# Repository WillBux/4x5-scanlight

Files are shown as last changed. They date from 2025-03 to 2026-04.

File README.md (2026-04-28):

# A Better Large Format Light Source For Scanning Color Negative Film

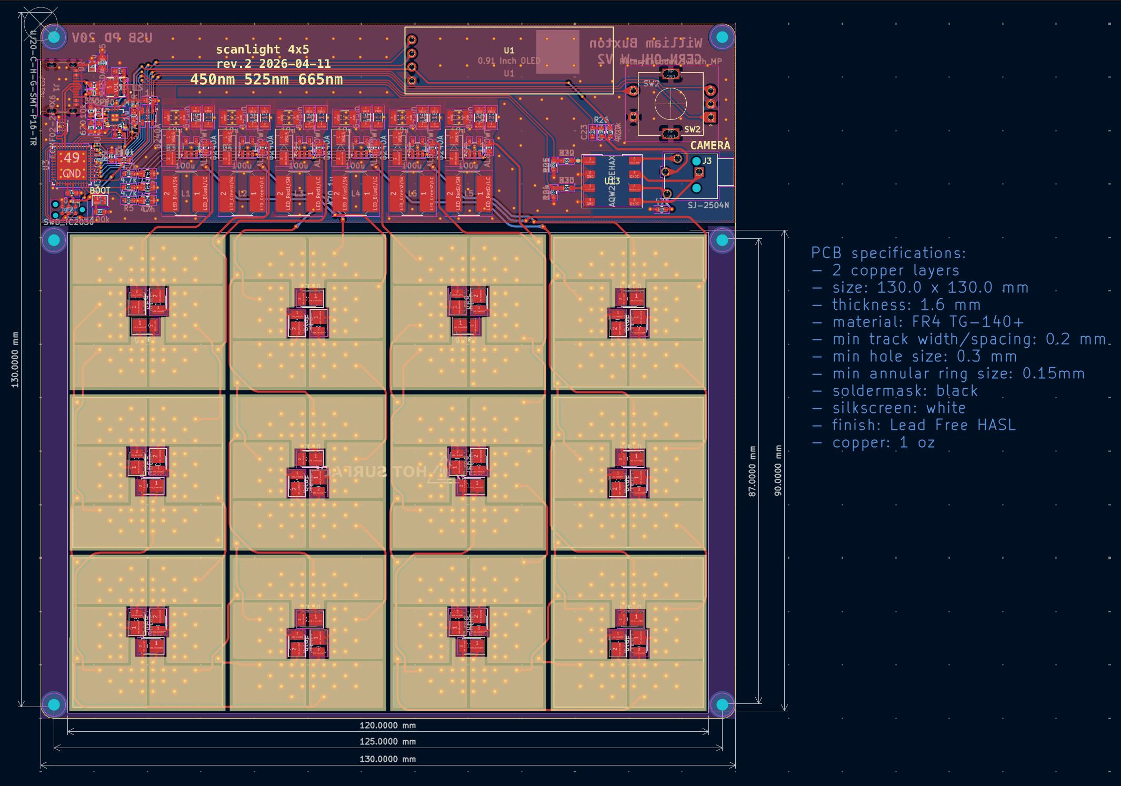
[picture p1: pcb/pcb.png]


<small>Originally published by [jackw01](https://github.com/jackw01/scanlight) on 2024-08-05, forked 2025-03-20</small>

## tl;dr

Read [Jack's GitHub Page](https://jackw01.github.io/scanlight/) for the theory behind the project.

# Major Changes

This fork is a major redesign of the Scanlight project. 
The main purpose is to expand the size to allow for scanning 4x5 large format film. 

The number of LEDs have been doubled to 12 per color (deep red 660nm; green 525nm; royal blue 450nm) and the 3D printed shroud has been adjusted likewise.
A slightly different [red led](https://www.digikey.ch/en/products/detail/lumileds/L1SP-DRD0002800000/9805570) has been chosen 
to better match the [Spectral-Sensitivity Curve of Portra 160](https://business.kodakmoments.com/sites/default/files/files/resources/e4051_Portra_160.pdf) (and it is cheaper at the time of writing).

This project incorporates a microcontroller (STM32G0B1) which more precisely controls the brightness of each LED channel.
Brightness values can be stored through power off states for repeatable scans. 
Additionally, the microcontroller is responsible for USB-PD (20V is necessary, ~1.25A required for maximum brightness)



[Schematic (PDF)](pcb/schematic.pdf)

[BOM](pcb/bom/ibom.html)

#### Build Notes

The PCB should be fabricated similar to [jackw01/scanlight](https://github.com/jackw01/scanlight), that is a black soldermask and white silkscreen. 

As modified, only a 20V-capable USB PD supply can be used. All parts were sourced on DigiKey.

### The Diffuser

The diffuser stack up has not changed from [jackw01/scanlight](https://github.com/jackw01/scanlight).
Only the 3D printed enclosure has been enlarged. 

I printed the parts in black PETG and installed aluminum tape on the insides to improve efficiency.

Additional parts: 
- 4x M2x6mm socket head cap screws
- 4x M2x10mm socket head cap screws
- 8x M2 square nuts (DIN 562)

### Status and the Future

The backlight has been working great for my scanning! 
I recently redesigned the PCB to add a 2.5mm jack output for a shutter sync.
This enables the ability to scan automatically with separate RGB channels.
This feature is enabled when the 2.5mm jack is plugged in.
I will update the README when my PCBs arrive and I successfully test the feature. 

In the distant future I plan on incorporating this into my enlarger to print 4x5 (and 120) negatives.
I no longer shoot 35mm and probably will not produce a 35mm mask for scanning and printing.
If you only shoot 35mm I recommend using Jack's design as it is smaller and cheaper. 

## license

The PCB schematic, layout, and Gerber files and the 3D CAD files for this project are released under the CERN Open Hardware Licence Version 2 - Weakly Reciprocal (CERN-OHL-W V2).

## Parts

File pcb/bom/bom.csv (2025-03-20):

Reference | Value | Footprint | Qty | DNP | MPN
C1,C2 | 330p | Capacitor_SMD:C_0603_1608Metric | 2 |  | Generic 330pF 50V C0G/NP0 0603
C3 | 4.7u | Capacitor_SMD:C_0805_2012Metric | 1 |  | Generic 4.7uF 50V X7R 0805
C4,C8,C9,C14,C15,C18,C19,C22 | 1u | Capacitor_SMD:C_0603_1608Metric | 8 |  | Generic 1uF 50V X7R 0603 X7R
C5,C6 | 0.1u | Capacitor_SMD:C_0603_1608Metric | 2 |  | Generic 0.1uF 50V X7R 0603
C7,C11,C13 | 47n | Capacitor_SMD:C_0805_2012Metric | 3 |  | Generic 0.047uF 50V X7R 0805
C10,C12,C16,C17,C20,C21 | 10u | Capacitor_SMD:C_1210_3225Metric | 6 |  | Generic 10uF 50V X7R 1210
D1 | BAT54K | Diode_SMD:D_SOD-523 | 1 |  | BAT54KFILM
D2 | ESDA25P35 | Diode_SMD:ST_QFN-2L_1.6x1.0mm | 1 |  | ESDA25P35-1U1M
D3,D4,D6,D7,D8,D21 | B240A | Diode_SMD:D_SMA | 6 |  | B240A-13-F
D5,D9,D12,D15,D20,D24,D27,D31,D34,D38,D41,D44 | red | LED_SMD:LED_PLCC_2835_Handsoldering_Reverse | 12 |  | L1SP-DRD0002800000
D10,D13,D17,D18,D22,D25,D29,D32,D33,D37,D39,D43 | green | LED_SMD:LED_PLCC_2835_Handsoldering | 12 |  | JE2835AGR-N-0002A0000-N0000001
D11,D14,D16,D19,D23,D26,D28,D30,D35,D36,D40,D42 | blue | LED_SMD:LED_PLCC_2835_Handsoldering | 12 |  | JE2835ARY-N-0002A0000-N0000001
J1 | UJ20-C-H-G-SMT-P16-TR | Custom:USB_C_Receptacle_UJ20-C-H-G-SMT-P16-TR | 1 |  | UJ20-C-H-G-SMT-P16-TR
J2 | SWD_TC2030 | Connector:Tag-Connect_TC2030-IDC-NL_2x03_P1.27mm_Vertical | 1
L1,L2,L3,L4,L5,L6 | 100u | Inductor_SMD:L_Bourns_SRN8040TA | 6 |  | HPC 8040NV-101M
Q1 | STL11N3LLH6 | Custom:POWERFLAT-3p3X3p3_STM | 1 |  | STL11N3LLH6
R1,R10 | 10k | Resistor_SMD:R_0603_1608Metric | 2 |  | Generic 10kΩ 5% 0603
R2 | 100k | Resistor_SMD:R_0603_1608Metric | 1 |  | Generic 100kΩ 1% 0603
R3 | 620 | Resistor_SMD:R_0603_1608Metric | 1 |  | Generic 620Ω 1% 0603
R4 | 200k | Resistor_SMD:R_0603_1608Metric | 1 |  | Generic 200kΩ 1% 0603
R5,R7,R8 | 4.7k | Resistor_SMD:R_0603_1608Metric | 3 |  | Generic 4.7kΩ 1% 0603
R6,R11,R12,R13,R14,R15,R16,R17,R18,R19,R20,R21 | 845m | Resistor_SMD:R_1206_3216Metric | 12 |  | Generic 845mΩ 1% 1206
R9 | 40.2k | Resistor_SMD:R_0603_1608Metric | 1 |  | Generic 40.2kΩ 1% 0603
SW1 | BOOT | Jumper:SolderJumper-2_P1.3mm_Open_TrianglePad1.0x1.5mm | 1
SW2 | RotaryEncoder_Switch_MP | Rotary_Encoder:RotaryEncoder_Alps_EC11E-Switch_Vertical_H20mm | 1 |  | EC11E
U1 | 0.91 Inch OLED | Display:0.91_Inch_OLED | 1 |  | Monochrome OLED 0.91" 128x32 (Aliexpress)
U2 | ECMF02-2AMX6 | Package_DFN_QFN:ST_UQFN-6L_1.5x1.7mm_P0.5mm | 1 |  | ECMF02-2AMX6
U3 | STM32G0B1CBUx | Package_DFN_QFN:QFN-48-1EP_7x7mm_P0.5mm_EP5.6x5.6mm | 1 |  | STM32G0B1CBU6
U4 | TCPP01_M12 | Custom:QFN-12-1EP_3x3mm_P0.50mm_EP1.45x1.45mm | 1 |  | TCPP01_M12
U5,U7,U8,U9,U10,U11 | AL8860WT | Package_TO_SOT_SMD:TSOT-23-5 | 6 |  | AL8860WT-7
U6 | ST732M33R | Package_TO_SOT_SMD:TSOT-23-5 | 1 |  | ST732M33R

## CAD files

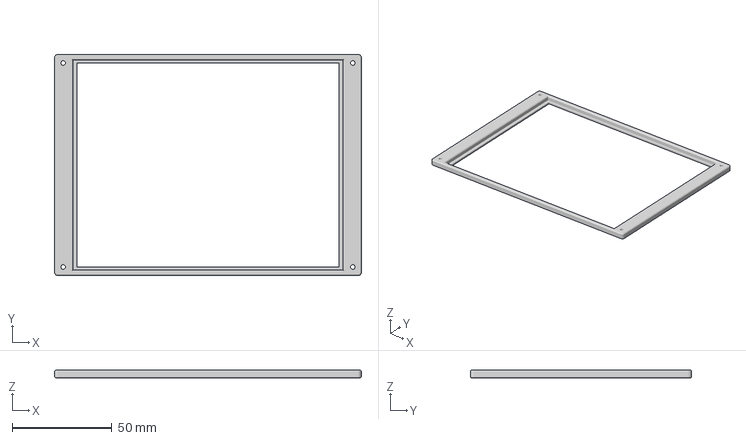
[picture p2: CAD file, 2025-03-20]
3d/Frame.3mf
153.5 x 110.7 x 4.00 mm

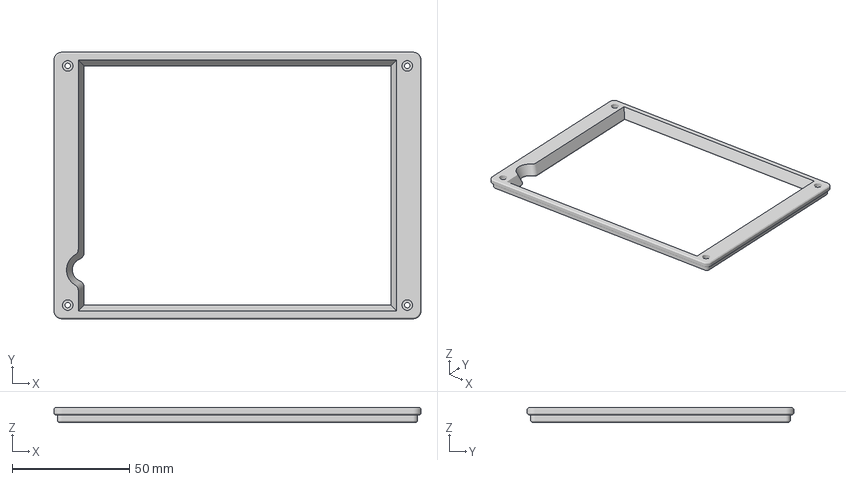
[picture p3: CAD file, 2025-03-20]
3d/CoverPlate.3mf
156.5 x 113.7 x 6.20 mm

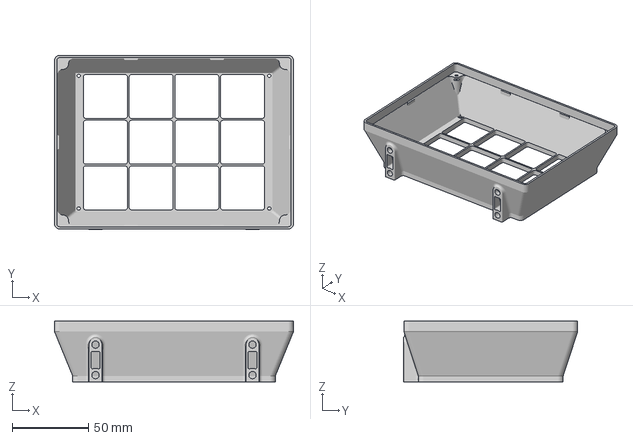
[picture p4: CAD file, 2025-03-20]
3d/Housing.3mf
156.8 x 114.4 x 40.0 mm

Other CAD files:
3d/scanlight.f3z

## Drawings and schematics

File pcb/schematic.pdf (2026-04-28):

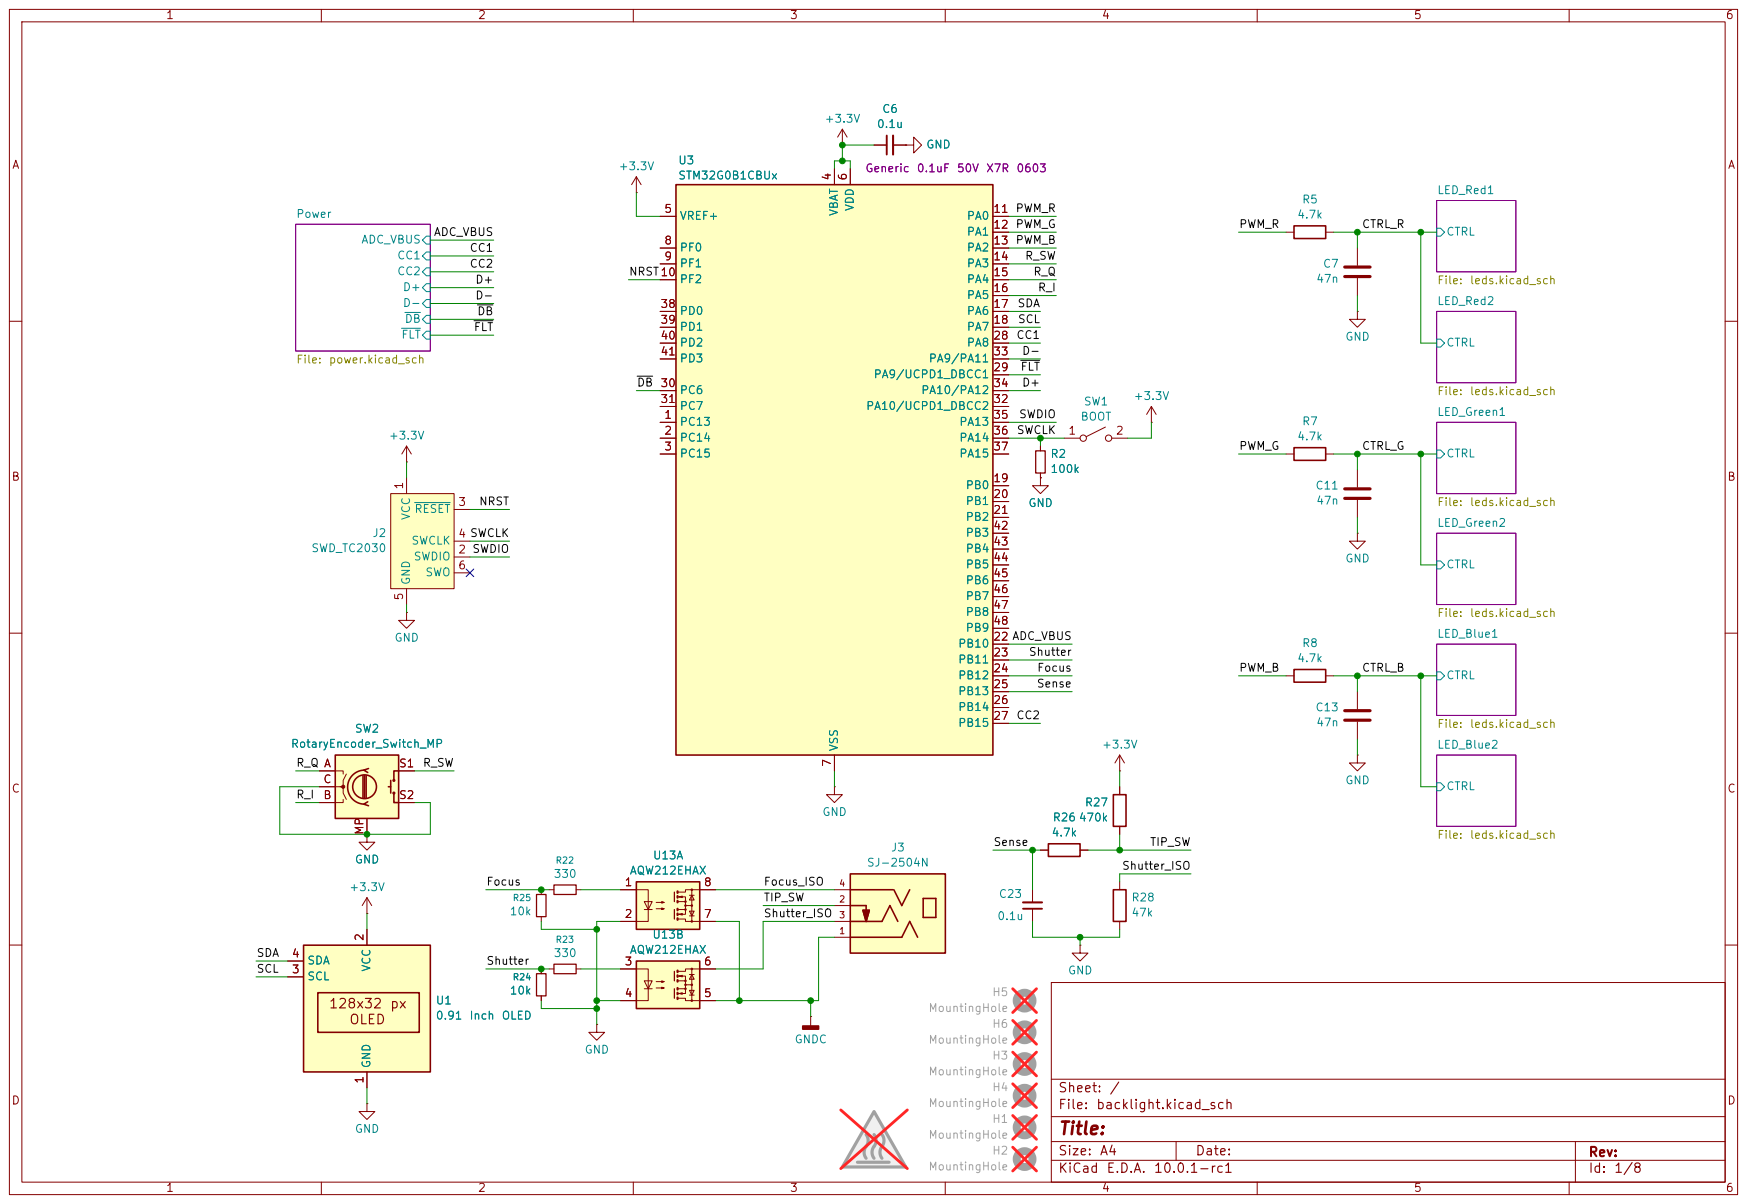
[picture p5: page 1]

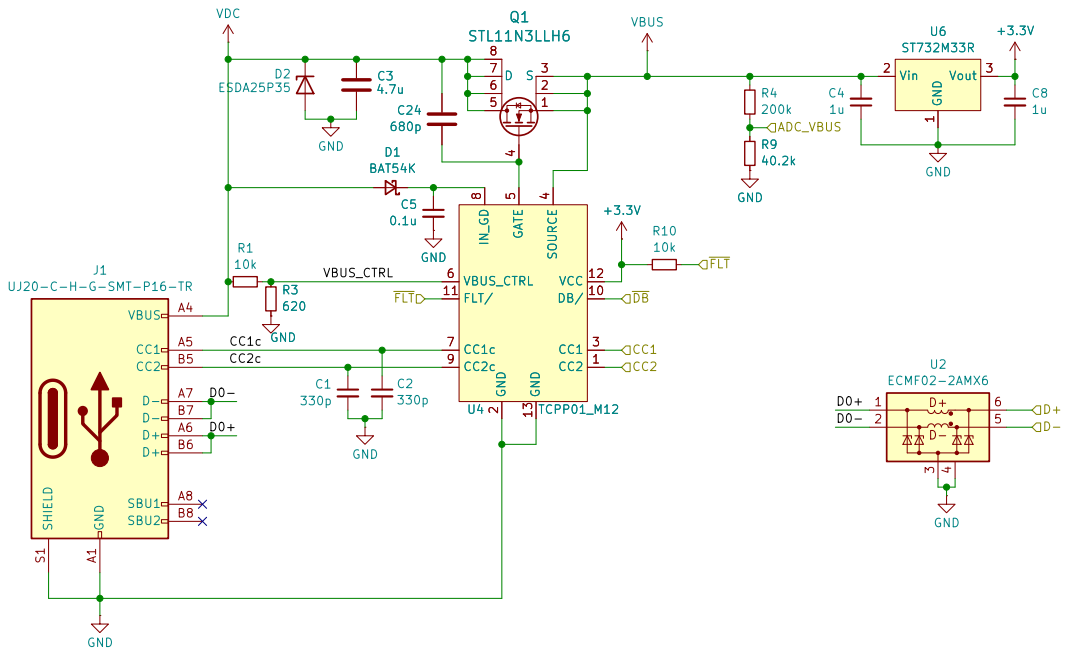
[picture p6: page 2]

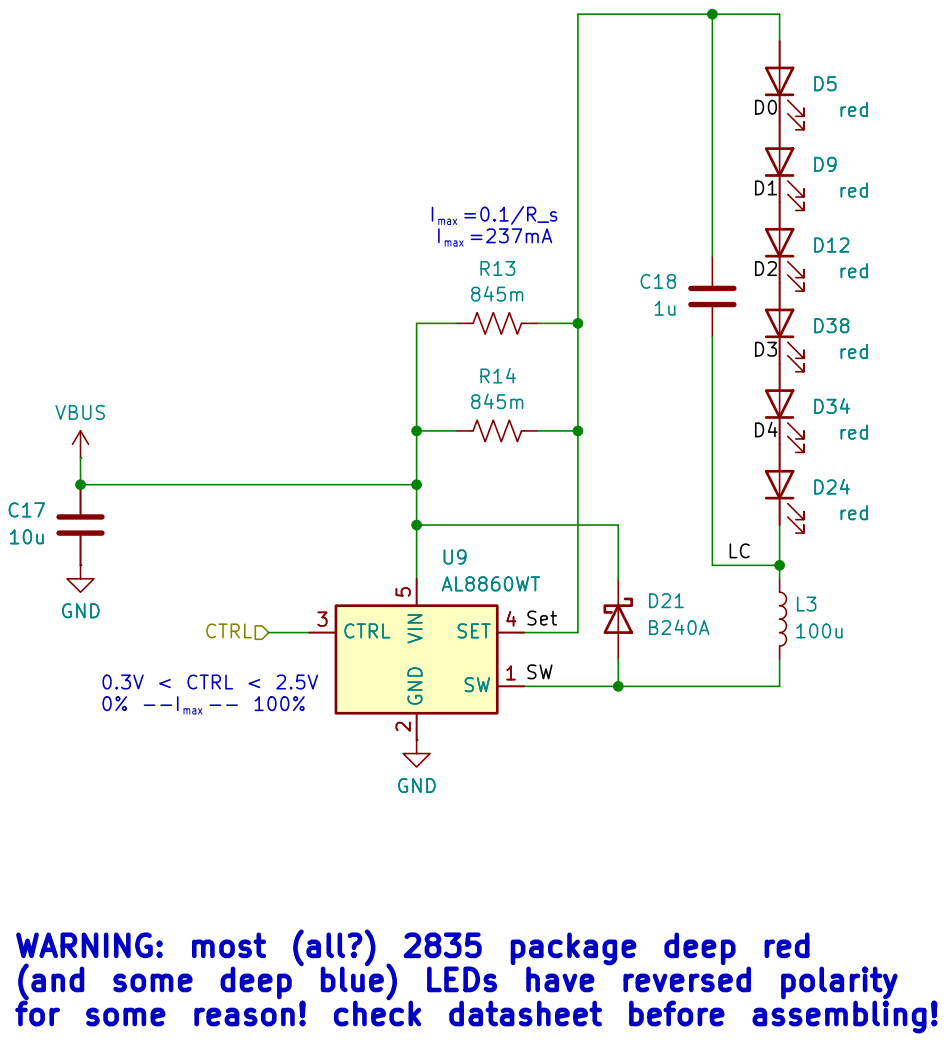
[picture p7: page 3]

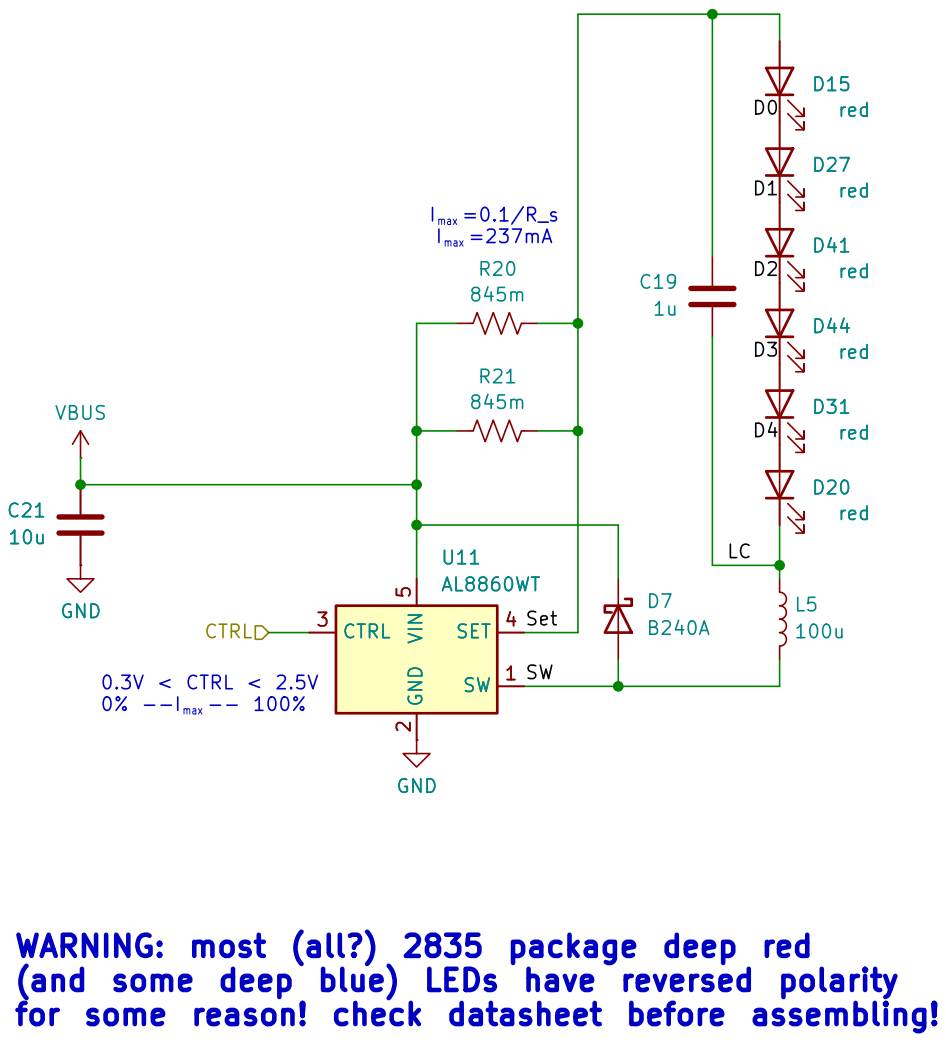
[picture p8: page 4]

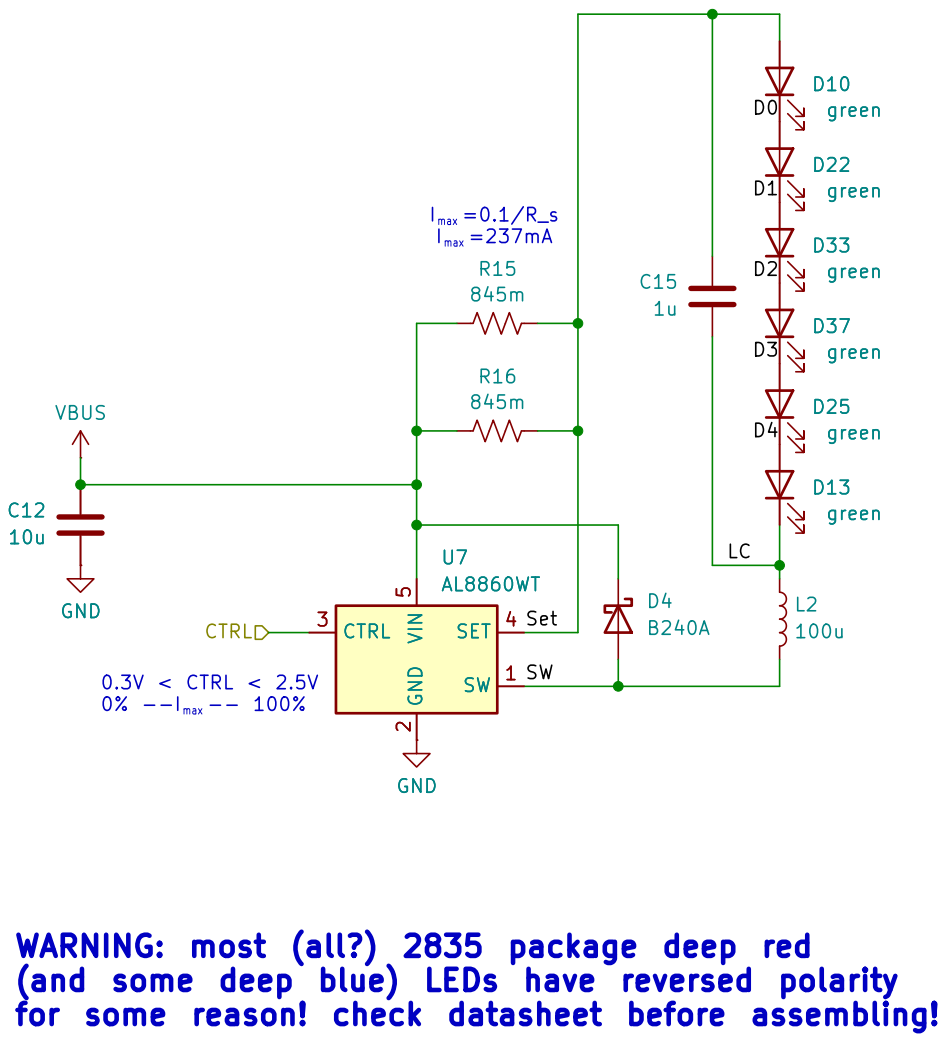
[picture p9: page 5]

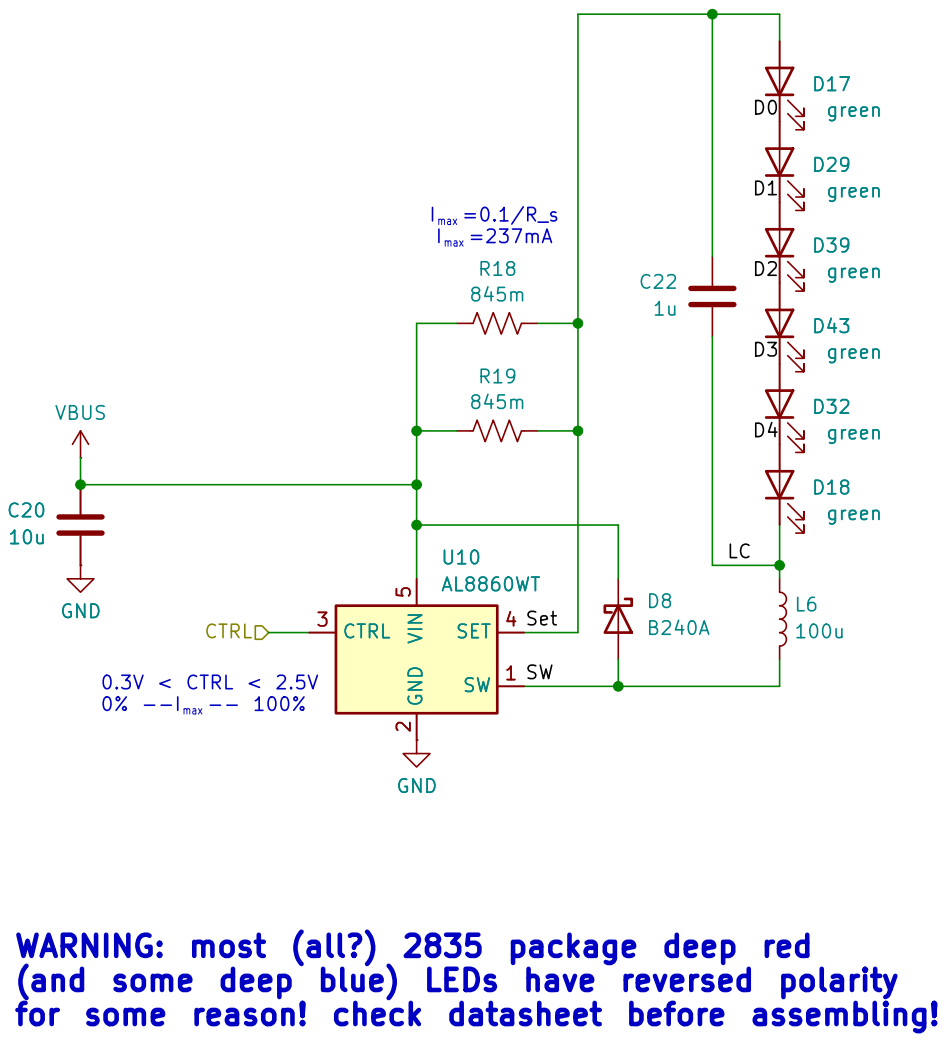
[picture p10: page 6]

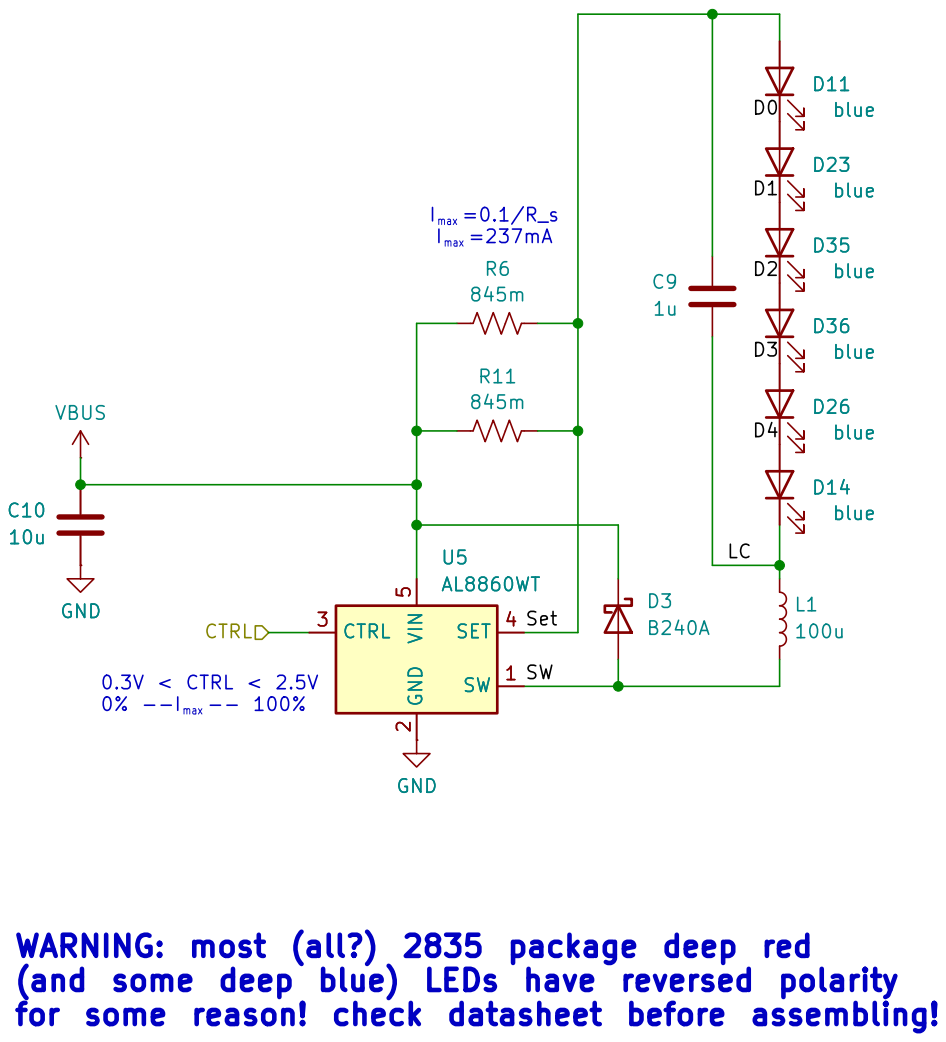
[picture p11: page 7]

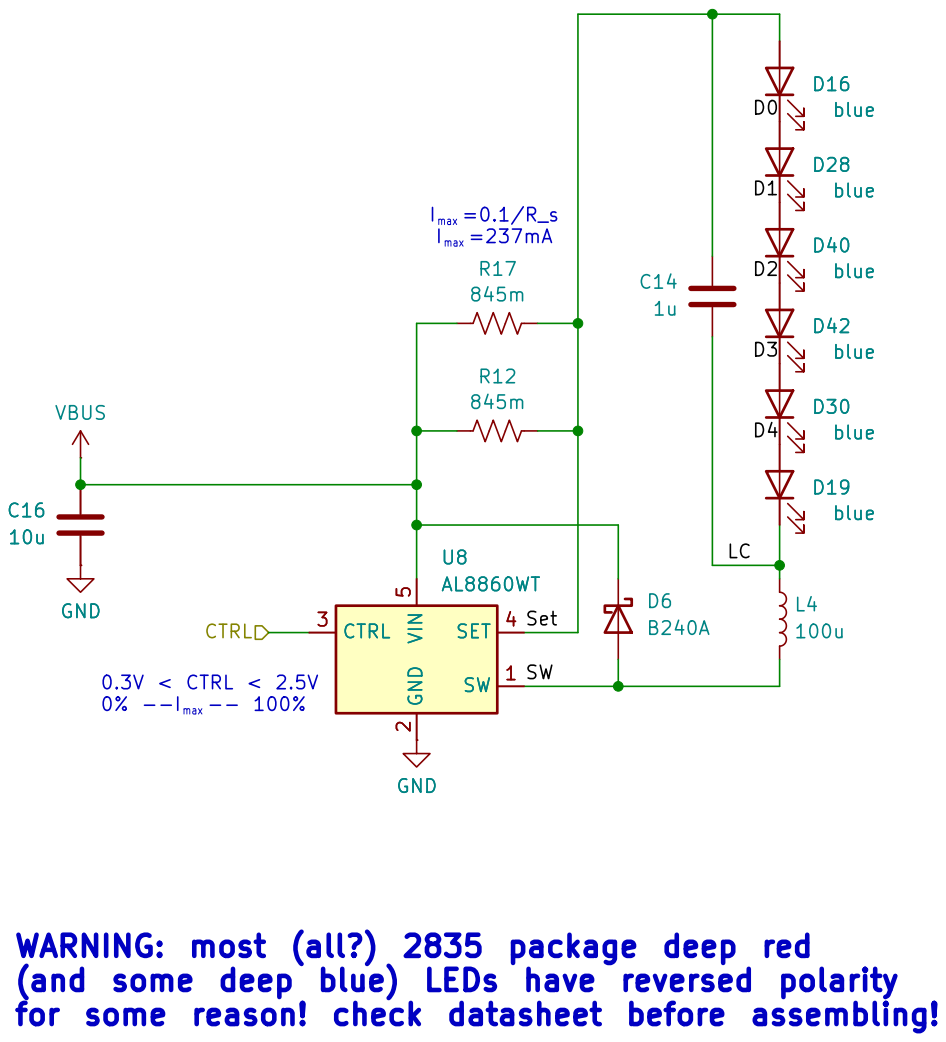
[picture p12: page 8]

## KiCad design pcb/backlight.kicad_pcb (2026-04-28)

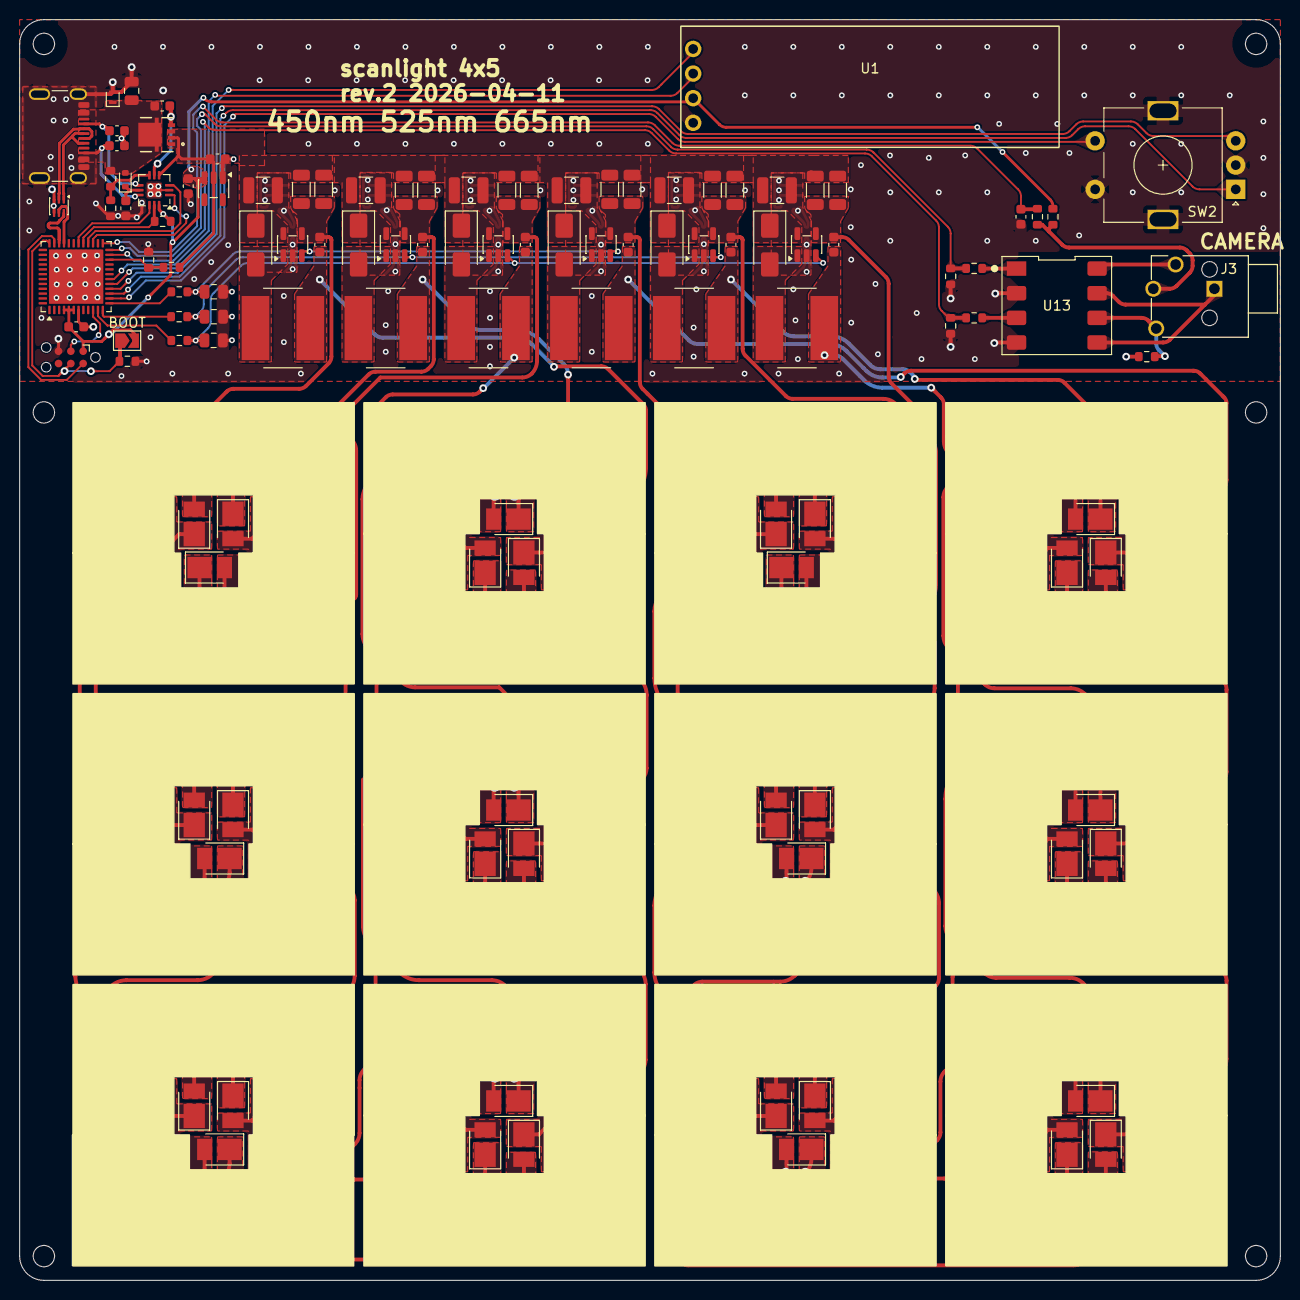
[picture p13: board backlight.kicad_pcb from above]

Board: 2 copper layers, 130.0 x 130.0 mm, 127 parts (1 on the bottom side), 89 nets.

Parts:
C1, C2: 330p; C_0603_1608Metric
C3: 4.7u; C_0805_2012Metric
C4, C8, C9, C14, C15, C18, C19, C22: 1u; C_0603_1608Metric
C5, C6, C23: 0.1u; C_0603_1608Metric
C7, C11, C13: 47n; C_0805_2012Metric
C10, C12, C16, C17, C20, C21: 10u; C_1210_3225Metric
C24: 680p; C_0603_1608Metric
D1: BAT54K; D_SOD-523
D2: ESDA25P35; ST_QFN-2L_1.6x1.0mm
D3, D4, D6, D7, D8, D21: B240A; D_SMA
D5, D9, D12, D15, D20, D24, D27, D31, D34, D38, D41, D44: red; LED_PLCC_2835_Handsoldering_Reverse
D10, D13, D17, D18, D22, D25, D29, D32, D33, D37, D39, D43: green; LED_PLCC_2835_Handsoldering
D11, D14, D16, D19, D23, D26, D28, D30, D35, D36, D40, D42: blue; LED_PLCC_2835_Handsoldering
H1, H2, H3, H4, H5, H6: MountingHole; MountingHole_2.2mm_M2_Mask_5mm
J1: UJ20-C-H-G-SMT-P16-TR; USB_C_Receptacle_UJ20-C-H-G-SMT-P16-TR
J2: SWD_TC2030; Tag-Connect_TC2030-IDC-NL_2x03_P1.27mm_Vertical
J3: SJ-2504N; CUI_SJ-2504N
L1, L2, L3, L4, L5, L6: 100u; L_Bourns_SRN8040TA
Q1: STL11N3LLH6; POWERFLAT-3p3X3p3_STM
R1, R10, R24, R25: 10k; R_0603_1608Metric
R2: 100k; R_0603_1608Metric
R3: 620; R_0603_1608Metric
R4: 200k; R_0603_1608Metric
R5, R7, R8, R26: 4.7k; R_0603_1608Metric
R6, R11, R12, R13, R14, R15, R16, R17, R18, R19, R20, R21: 845m; R_1206_3216Metric
R9: 40.2k; R_0603_1608Metric
R22, R23: 330; R_0603_1608Metric
R27: 470k; R_0603_1608Metric
R28: 47k; R_0603_1608Metric
SW1: BOOT; SolderJumper-2_P1.3mm_Open_TrianglePad1.0x1.5mm
SW2: RotaryEncoder_Switch_MP; RotaryEncoder_Alps_EC11E-Switch_Vertical_H20mm
SYM1: SYM_Hot_Large; HOT
U1: 0.91 Inch OLED; 0.91_OLED_Display
U2: ECMF02-2AMX6; ST_UQFN-6L_1.5x1.7mm_P0.5mm
U3: STM32G0B1CBUx; QFN-48-1EP_7x7mm_P0.5mm_EP5.6x5.6mm
U4: TCPP01_M12; QFN-12-1EP_3x3mm_P0.50mm_EP1.45x1.45mm
U5, U7, U8, U9, U10, U11: AL8860WT; TSOT-23-5
U6: ST732M33R; TSOT-23-5
U13: AQW212EHAX; DIP-8_W8.3_SMDSocket

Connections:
+3.3V: C6.1, C8.1, J2.1 (VCC), R10.1, R27.2, SW1.2 (B), U1.2 (VCC), U3.4 (VBAT), U3.5 (VREF+), U3.6 (VDD), U4.12 (VCC), U6.3 (Vout)
/ADC_VBUS: R4.2, R9.1, U3.22 (PB10)
/CC1: U3.28 (PA8), U4.3 (CC1)
/CC2: U3.27 (PB15), U4.1 (CC2)
/CTRL_B: C13.1, R8.1, U5.3 (CTRL), U8.3 (CTRL)
/CTRL_G: C11.1, R7.1, U7.3 (CTRL), U10.3 (CTRL)
/CTRL_R: C7.1, R5.1, U9.3 (CTRL), U11.3 (CTRL)
/D+: U2.6 (D+_out), U3.34 (PA10/PA12)
/D-: U2.5 (D-_out), U3.33 (PA9/PA11)
/Focus: R22.2, R25.1, U3.24 (PB12)
/Focus_ISO: J3.4, U13.8
/LED_Blue1/D0: D11.1 (K), D23.2 (A)
/LED_Blue1/D1: D23.1 (K), D35.2 (A)
/LED_Blue1/D2: D35.1 (K), D36.2 (A)
/LED_Blue1/D3: D26.2 (A), D36.1 (K)
/LED_Blue1/D4: D14.2 (A), D26.1 (K)
/LED_Blue1/LC: C9.2, D14.1 (K), L1.1
/LED_Blue1/SW: D3.2 (A), L1.2, U5.1 (SW)
/LED_Blue1/Set: C9.1, D11.2 (A), R6.2, R11.2, U5.4 (SET)
/LED_Blue2/D0: D16.1 (K), D28.2 (A)
/LED_Blue2/D1: D28.1 (K), D40.2 (A)
/LED_Blue2/D2: D40.1 (K), D42.2 (A)
/LED_Blue2/D3: D30.2 (A), D42.1 (K)
/LED_Blue2/D4: D19.2 (A), D30.1 (K)
/LED_Blue2/LC: C14.2, D19.1 (K), L4.1
/LED_Blue2/SW: D6.2 (A), L4.2, U8.1 (SW)
/LED_Blue2/Set: C14.1, D16.2 (A), R12.2, R17.2, U8.4 (SET)
/LED_Green1/D0: D10.1 (K), D22.2 (A)
/LED_Green1/D1: D22.1 (K), D33.2 (A)
/LED_Green1/D2: D33.1 (K), D37.2 (A)
/LED_Green1/D3: D25.2 (A), D37.1 (K)
/LED_Green1/D4: D13.2 (A), D25.1 (K)
/LED_Green1/LC: C15.2, D13.1 (K), L2.1
/LED_Green1/SW: D4.2 (A), L2.2, U7.1 (SW)
/LED_Green1/Set: C15.1, D10.2 (A), R15.2, R16.2, U7.4 (SET)
/LED_Green2/D0: D17.1 (K), D29.2 (A)
/LED_Green2/D1: D29.1 (K), D39.2 (A)
/LED_Green2/D2: D39.1 (K), D43.2 (A)
/LED_Green2/D3: D32.2 (A), D43.1 (K)
/LED_Green2/D4: D18.2 (A), D32.1 (K)
/LED_Green2/LC: C22.2, D18.1 (K), L6.1
/LED_Green2/SW: D8.2 (A), L6.2, U10.1 (SW)
/LED_Green2/Set: C22.1, D17.2 (A), R18.2, R19.2, U10.4 (SET)
/LED_Red1/D0: D5.1 (K), D9.2 (A)
/LED_Red1/D1: D9.1 (K), D12.2 (A)
/LED_Red1/D2: D12.1 (K), D38.2 (A)
/LED_Red1/D3: D34.2 (A), D38.1 (K)
/LED_Red1/D4: D24.2 (A), D34.1 (K)
/LED_Red1/LC: C18.2, D24.1 (K), L3.1
/LED_Red1/SW: D21.2 (A), L3.2, U9.1 (SW)
/LED_Red1/Set: C18.1, D5.2 (A), R13.2, R14.2, U9.4 (SET)
/LED_Red2/D0: D15.1 (K), D27.2 (A)
/LED_Red2/D1: D27.1 (K), D41.2 (A)
/LED_Red2/D2: D41.1 (K), D44.2 (A)
/LED_Red2/D3: D31.2 (A), D44.1 (K)
/LED_Red2/D4: D20.2 (A), D31.1 (K)
/LED_Red2/LC: C19.2, D20.1 (K), L5.1
/LED_Red2/SW: D7.2 (A), L5.2, U11.1 (SW)
/LED_Red2/Set: C19.1, D15.2 (A), R20.2, R21.2, U11.4 (SET)
/NRST: J2.3 (~RESET), U3.10 (PF2)
/PWM_B: R8.2, U3.13 (PA2)
/PWM_G: R7.2, U3.12 (PA1)
/PWM_R: R5.2, U3.11 (PA0)
/Power/CC1c: C2.1, J1.A5 (CC1), U4.7 (CC1c)
/Power/CC2c: C1.1, J1.B5 (CC2), U4.9 (CC2c)
/Power/D0+: J1.A6 (D+), J1.B6 (D+), U2.1 (D+_in)
/Power/D0-: J1.A7 (D-), J1.B7 (D-), U2.2 (D-_in)
/Power/VBUS_CTRL: R1.2, R3.1, U4.6 (VBUS_CTRL)
/R_I: SW2.B, U3.16 (PA5)
/R_Q: SW2.A, U3.15 (PA4)
/R_SW: SW2.S1, U3.14 (PA3)
/SCL: U1.3 (SCL), U3.18 (PA7)
/SDA: U1.4 (SDA), U3.17 (PA6)
/SWCLK: J2.4 (SWCLK), R2.1, SW1.1 (A), U3.36 (PA14)
/SWDIO: J2.2 (SWDIO), U3.35 (PA13)
/Sense: C23.2, R26.2, U3.25 (PB13)
/Shutter: R23.2, R24.1, U3.23 (PB11)
/Shutter_ISO: J3.3, R28.1, U13.6
/TIP_SW: J3.2, R26.1, R27.1
/~DB: U3.30 (PC6), U4.10 (DB/)
/~FLT: R10.2, U3.29 (PA9/UCPD1_DBCC1), U4.11 (FLT/)
GND: C1.2, C2.2, C3.1, C4.1, C5.2, C6.2, C7.2, C8.2, C10.2, C11.2, C12.2, C13.2, C16.2, C17.2, C20.2, C21.2, C23.1, D2.2 (A), J1.A1 (GND), J1.A12 (GND), J1.B1 (GND), J1.B12 (GND), J1.S1 (SHIELD), J2.5 (GND), R2.2, R3.2, R9.2, R24.2, R25.2, R28.2, SW2.C, SW2.MP, SW2.S2, U1.1 (GND), U2.3 (GND), U2.4 (NC), U3.7 (VSS), U3.49 (VSS), U4.2 (GND), U4.13 (GND), U5.2 (GND), U6.1 (GND), U7.2 (GND), U8.2 (GND), U9.2 (GND), U10.2 (GND), U11.2 (GND), U13.2, U13.4
GNDC: J3.1, U13.5, U13.7
unnamed: C5.1, D1.1 (K), U4.8 (IN_GD)
unnamed: R22.1, U13.1
unnamed: R23.1, U13.3
unnamed: C24.2, Q1.4, U4.5 (GATE)
VBUS: C4.2, C10.1, C12.1, C16.1, C17.1, C20.1, C21.1, D3.1 (K), D4.1 (K), D6.1 (K), D7.1 (K), D8.1 (K), D21.1 (K), Q1.1, Q1.2, Q1.3 (S), R4.1, R6.1, R11.1, R12.1, R13.1, R14.1, R15.1, R16.1, R17.1, R18.1, R19.1, R20.1, R21.1, U4.4 (SOURCE), U5.5 (VIN), U6.2 (Vin), U7.5 (VIN), U8.5 (VIN), U9.5 (VIN), U10.5 (VIN), U11.5 (VIN)
VDC: C3.2, C24.1, D1.2 (A), D2.1 (K), J1.A4 (VBUS), J1.A9 (VBUS), J1.B4 (VBUS), J1.B9 (VBUS), Q1.5, Q1.6, Q1.7 (D), Q1.8, R1.1

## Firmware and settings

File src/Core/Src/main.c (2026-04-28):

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
/* Includes ------------------------------------------------------------------*/
#include "main.h"
#include "cmsis_os.h"
#include "app_tcpp.h"
#include "usbpd.h"
#include "usb_device.h"

/* USER CODE BEGIN Includes */
#include "usbd_cdc_if.h"
#include <stdio.h>

// include custom defines before library to preserve overrides
#include "ssd1306_custom_defines.h" 
#include "ssd1306.h"
#include "eeprom_emul.h"
#include "usbpd_pwr_user.h"

/* USER CODE END Includes */

/* USER CODE BEGIN PD */
#define DEBOUNCE_DELAY 2 // milliseconds
#define BUTTON_DEBOUNCE_MS 15
#define BOOTLOADER_ADDRESS 0x1FFF0000
#define BOOTLOADER_FLAG_VALUE 0xDEADBEEF
#define BOOTLOADER_BUTTON_HOLD_MS 1500U
#define USBPD_20V_LOCKOUT_ASSERT_MV 19000U
#define USBPD_20V_LOCKOUT_RELEASE_MV 19500U
#define CAMERA_DETECT_DEBOUNCE_MS 25U
#define CAMERA_DETECT_INSERTED_LEVEL GPIO_PIN_SET
#define PWM_TIMER_PERIOD 148U
#define PWM_INPUT_MAX 100U
#define LED_CTRL_MIN_MV 300U
#define LED_CTRL_MAX_MV 2500U
/* USER CODE END PD */

ADC_HandleTypeDef hadc1;

I2C_HandleTypeDef hi2c2;
DMA_HandleTypeDef hdma_i2c2_tx;

IWDG_HandleTypeDef hiwdg;

TIM_HandleTypeDef htim2;

/* Definitions for defaultTask */
osThreadId_t defaultTaskHandle;
const osThreadAttr_t defaultTask_attributes = {
  .name = "defaultTask",
  .priority = (osPriority_t) osPriorityNormal,
  .stack_size = 128 * 4
};
/* USER CODE BEGIN PV */
extern int _bflag; // boot flag
uint32_t *dfu_boot_flag;
typedef void (*pFunction)(void);
pFunction JumpToApplication;
uint32_t JumpAddress;

#define MAX_DISPLAY_TXT 20
char display_txt[MAX_DISPLAY_TXT];

// Rotary encoder vars
volatile uint8_t colors[3] = { 0, 0, 0 };
volatile uint8_t pwm[3] = { 0, 0, 0 };
/* Smallest period that provides unique PWM counts for UI 0..100 while
 * keeping 1..99 mapped across the 0.3V..2.5V analog dimming region.
 */
const uint8_t PWM_DUTY_LOOKUP[PWM_INPUT_MAX + 1] = { 0, 14, 15, 16, 17, 18, 19,
		20, 21, 22, 23, 24, 25, 26, 27, 28, 29, 30, 31, 32, 33, 34, 35, 36,
		37, 38, 39, 40, 41, 42, 43, 44, 45, 46, 47, 48, 49, 50, 51, 52, 53,
		54, 55, 56, 57, 58, 59, 60, 61, 62, 63, 64, 65, 66, 67, 68, 69, 70,
		71, 72, 73, 74, 75, 76, 77, 78, 79, 80, 81, 82, 83, 84, 85, 86, 87,
		88, 89, 90, 91, 92, 93, 94, 95, 96, 97, 98, 99, 100, 101, 102, 103,
		104, 105, 106, 107, 108, 109, 110, 111, 112, 148 };
volatile uint8_t select;
volatile uint8_t on = 0;
volatile uint8_t save_no = 0;
uint8_t pd_20v_ready = 0;
uint8_t camera_mode_active = 0;
uint8_t camera_detect_last_sample = 0;
uint32_t camera_detect_last_transition = 0;

void EncoderTask(void *argument);

osThreadId_t encoderTaskHandle;
const osThreadAttr_t encoderTask_attributes = { .name = "encoderTask",
		.priority = (osPriority_t) osPriorityNormal1, .stack_size = 256 * 4 };

// Gray code state table
const int8_t rotary_table[16] = { 0, -1, +1, 0, +1, 0, 0, -1, -1, 0, 0, +1, 0,
		+1, -1, 0 };

const uint8_t ULINE_X[5] = { 14, 56, 98, 0, 35 };
const uint8_t ULINE_Y[5] = { 10, 10, 10, 20, 20 };
const uint8_t ULINE_LEN[5] = { 21, 21, 21, 21, 28 };

// EEPROM
EE_Status ee_status = EE_OK;
uint32_t eeprom_read;
__IO uint32_t ErasingOnGoing = 0;

/* USER CODE END PV */

void SystemClock_Config(void);
static void MX_GPIO_Init(void);
static void MX_DMA_Init(void);
static void MX_ADC1_Init(void);
static void MX_I2C2_Init(void);
static void MX_TIM2_Init(void);
static void MX_UCPD1_Init(void);
static void MX_IWDG_Init(void);
static void MX_CRC_Init(void);
void StartDefaultTask(void *argument);

/* USER CODE BEGIN 0 */
/**
 * @brief  FLASH end of operation interrupt callback.
 * @param  ReturnValue: The value saved in this parameter depends on the ongoing procedure
 *                  Mass Erase: Bank number which has been requested to erase
 *                  Page Erase: Page which has been erased
 *                  Program: Address which was selected for data program
 * @retval None
 */
void HAL_FLASH_EndOfOperationCallback(uint32_t ReturnValue) {
	/* Call CleanUp callback when all requested pages have been erased */
	if ((ReturnValue == (START_PAGE + PAGES_NUMBER / 2 - 1))
			|| (ReturnValue == (START_PAGE + PAGES_NUMBER - 1))) {
		EE_EndOfCleanup_UserCallback();
	}
}

/**
 * @brief  Clean Up end of operation interrupt callback.
 * @param  None
 * @retval None
 */
void EE_EndOfCleanup_UserCallback(void) {
	ErasingOnGoing = 0;
}

void InitDisplay(void) {
	ssd1306_Init();
	ssd1306_FlipScreenVertically();
	ssd1306_Clear();
	ssd1306_SetColor(White);
	ssd1306_UpdateScreen();
	HAL_Delay(10);
}

uint8_t bootloaderButtonHeldAtStartup(void) {
	uint32_t start_tick;

	if (HAL_GPIO_ReadPin(R_SW_GPIO_Port, R_SW_Pin) != GPIO_PIN_RESET) {
		return 0U;
	}

	start_tick = HAL_GetTick();
	while ((HAL_GetTick() - start_tick) < BOOTLOADER_BUTTON_HOLD_MS) {
		if (HAL_GPIO_ReadPin(R_SW_GPIO_Port, R_SW_Pin) != GPIO_PIN_RESET) {
			return 0U;
		}
	}

	return 1U;
}

void Bootloader_RequestReset(void) {
	*dfu_boot_flag = BOOTLOADER_FLAG_VALUE;
	__DSB();
	__ISB();
	HAL_NVIC_SystemReset();
	while (1) {
	}
}

void JumpToBootloader(void) {
	/* Wait any cleanup is completed before accessing flash again */
	while (ErasingOnGoing == 1) {
	}

	Bootloader_RequestReset();
}
// Overwrite printf for USB CDC
int _write(int file, char *ptr, int len) {
	CDC_Transmit_FS((uint8_t*) ptr, len);
	return len;
}

void USB_ProcessReceivedData(uint8_t *Buf, uint32_t Len) {
	CDC_Transmit_FS(Buf, Len); 	// echo input
	// check for boot flag 'b'
	for (uint32_t i = 0; i < Len; ++i) {
		if (Buf[i] == 0x62) { // `b`
			JumpToBootloader();
		}
	}
}

void refreshPDPowerState(void) {
	uint32_t vbus_mv = 0;
	if (BSP_ERROR_NONE == BSP_USBPD_PWR_VBUSGetVoltage(USBPD_PORT_0, &vbus_mv)) {
		if (pd_20v_ready == 0U) {
			pd_20v_ready =
					(vbus_mv >= USBPD_20V_LOCKOUT_RELEASE_MV) ? 1U : 0U;
		} else {
			pd_20v_ready =
					(vbus_mv >= USBPD_20V_LOCKOUT_ASSERT_MV) ? 1U : 0U;
		}
	} else {
		pd_20v_ready = 0U;
	}
}

uint8_t readCameraDetectState(void) {
	return (HAL_GPIO_ReadPin(CAMERA_DETECT_GPIO_Port, CAMERA_DETECT_Pin)
			== CAMERA_DETECT_INSERTED_LEVEL) ? 1U : 0U;
}

void refreshCameraModeState(void) {
	uint8_t sample = readCameraDetectState();
	uint32_t now = osKernelGetTickCount();

	if (sample != camera_detect_last_sample) {
		camera_detect_last_sample = sample;
		camera_detect_last_transition = now;
	}

	if ((camera_mode_active != camera_detect_last_sample)
			&& ((now - camera_detect_last_transition)
					>= CAMERA_DETECT_DEBOUNCE_MS)) {
		camera_mode_active = camera_detect_last_sample;
		if (camera_mode_active == 0U) {
			HAL_GPIO_WritePin(SHUTTER_GPIO_Port, SHUTTER_Pin, GPIO_PIN_RESET);
			HAL_GPIO_WritePin(FOCUS_GPIO_Port, FOCUS_Pin, GPIO_PIN_RESET);
		}
	}
}

uint8_t mapColorToPwmDuty(uint8_t color) {
	uint8_t idx = (color > PWM_INPUT_MAX) ? PWM_INPUT_MAX : color;
	return PWM_DUTY_LOOKUP[idx];
}

void voltageTooLow(void) {
	snprintf(display_txt, MAX_DISPLAY_TXT, "Need 20V USB-PD");
	ssd1306_SetCursor(0, 21);
	ssd1306_WriteString(display_txt, Font_7x10);
}

void displayEepromIssue() {
	snprintf(display_txt, MAX_DISPLAY_TXT, "EEPROM %i", ee_status);
	ssd1306_SetCursor(0, 12);
	ssd1306_WriteString(display_txt, Font_7x10);
	ssd1306_UpdateScreen();
}

void updateScreen() {
	ssd1306_Clear();
	snprintf(display_txt, MAX_DISPLAY_TXT, "R:%03u G:%03u B:%03u", colors[0],
			colors[1], colors[2]);
	ssd1306_SetCursor(0, 0);
	ssd1306_WriteString(display_txt, Font_7x10);
	if (save_no == 0) {
		snprintf(display_txt, MAX_DISPLAY_TXT, "%s  Save",
				on ? "ON " : "OFF");
	} else {
		snprintf(display_txt, MAX_DISPLAY_TXT, "%s  %s %u",
				on ? "ON " : "OFF",
				(save_no % 2 == 0) ? "Save" : "Read", (save_no + 1) / 2);
	}
	ssd1306_SetCursor(0, 11);
	ssd1306_WriteString(display_txt, Font_7x10);
	if (pd_20v_ready == 0U) {
		voltageTooLow();
	} else {
		snprintf(display_txt, MAX_DISPLAY_TXT, "PD OK  CAM:%s",
				camera_mode_active ? "ON" : "OFF");
		ssd1306_SetCursor(0, 21);
		ssd1306_WriteString(display_txt, Font_7x10);
	}
	ssd1306_DrawHorizontalLine(ULINE_X[select], ULINE_Y[select],
			ULINE_LEN[select]);
	ssd1306_UpdateScreen();
}

void EE_Read_Color(uint8_t address) {
	if (address > NB_OF_VARIABLES) {
		return;
	}
	/* Wait any cleanup is completed before accessing flash again */
	while (ErasingOnGoing == 1) {
	}
	ee_status = EE_ReadVariable32bits(address, &eeprom_read);
	if ((ee_status & EE_STATUSMASK_CLEANUP ) == EE_STATUSMASK_CLEANUP) {
		ErasingOnGoing = 1;
		ee_status |= EE_CleanUp();
	}
	if ((ee_status & EE_STATUSMASK_ERROR ) == EE_STATUSMASK_ERROR) {
		displayEepromIssue();
	}
	colors[0] = eeprom_read >> 0;
	colors[1] = eeprom_read >> 8;
	colors[2] = eeprom_read >> 16;
}

void EE_Write_Color(uint8_t address) {
	/* Wait any cleanup is completed before accessing flash again */
	while (ErasingOnGoing == 1) {
	}
	eeprom_read = colors[0] | colors[1] << 8 | colors[2] << 16;
	ee_status = EE_WriteVariable32bits(address, eeprom_read);
	if ((ee_status & EE_STATUSMASK_CLEANUP ) == EE_STATUSMASK_CLEANUP) {
		ErasingOnGoing = 1;
		ee_status |= EE_CleanUp();
	}
	if ((ee_status & EE_STATUSMASK_ERROR ) == EE_STATUSMASK_ERROR) {
		Error_Handler();
	}
}

void EncoderTask(void *argument) {
	uint8_t prev_IQ = ((HAL_GPIO_ReadPin(R_I_GPIO_Port, R_I_Pin) << 1)
			| HAL_GPIO_ReadPin(R_Q_GPIO_Port, R_Q_Pin));
	// for debounce button
	uint8_t lastBtn = HAL_GPIO_ReadPin(R_SW_GPIO_Port, R_SW_Pin);
	uint8_t btnStableState = lastBtn;
	uint32_t btnChangedTime = 0;
	uint8_t currBtn;

	// for rotary fsm
	uint8_t curr_I, curr_Q, curr_IQ;
	uint8_t index;
	int8_t delta = 0;

	for (;;) {
		// rotary FSM
		curr_I = HAL_GPIO_ReadPin(R_I_GPIO_Port, R_I_Pin);
		curr_Q = HAL_GPIO_ReadPin(R_Q_GPIO_Port, R_Q_Pin);
		curr_IQ = (curr_I << 1) | curr_Q;

		index = prev_IQ << 2 | curr_IQ;
		delta += rotary_table[index];

		if (rotary_table[index] != 0) {
			prev_IQ = curr_IQ;
		}

		if (delta >= 4) {
			// only add 1 if under 100
			if (select == 3) {
				on = 1;
			} else if (select == 4) {
				save_no += save_no > NB_OF_VARIABLES * 2 ? 0 : 1;
			} else if (colors[select] < 100) {
				++colors[select];
			}
			delta -= 4;
			//printf("Rot -1\n");
		} else if (delta <= -4) {
			// only subtract 1 if over 0
			if (select == 3) {
				on = 0;
			} else if (select == 4) {
				save_no -= save_no > 0 ? 1 : 0;
			} else if (colors[select] > 0) {
				--colors[select];
			}
			delta += 4;
			//printf("Rot +1\n");
		}

		// Button debounce
		currBtn = HAL_GPIO_ReadPin(R_SW_GPIO_Port, R_SW_Pin);
		if (currBtn != lastBtn) { // button state changed, restart debounce timer
			btnChangedTime = osKernelGetTickCount();
			lastBtn = currBtn;
		} else {
			// button state stable check if it's held long enough
			if (currBtn
					!= btnStableState&& (osKernelGetTickCount() - btnChangedTime) >= BUTTON_DEBOUNCE_MS) {
				btnStableState = currBtn;
				if (btnStableState == 0) {
					//button has been stable pressed
					if (select == 4 && save_no > 0) {
						if (save_no % 2 == 0) {
							EE_Write_Color((save_no + 1) / 2);
						} else {
							EE_Read_Color((save_no + 1) / 2);
						}
						save_no = 0;
					}
					select = (select + 1) % 5;
				}
			}
		}

		osDelay(DEBOUNCE_DELAY); // 2ms polling
	}
}

/* USER CODE END 0 */

/**
  * @brief  The application entry point.
  * @retval int
  */
int main(void)
{

  /* USER CODE BEGIN 1 */
	dfu_boot_flag = (uint32_t*) (&_bflag); // set in linker script
	if (*dfu_boot_flag == BOOTLOADER_FLAG_VALUE) {
		uint32_t bootloader_sp = *(__IO uint32_t*) BOOTLOADER_ADDRESS;
		*dfu_boot_flag = 0; // so next boot won't be affected
		/* Jump to system memory bootloader */
		JumpAddress = *(__IO uint32_t*) (BOOTLOADER_ADDRESS + 4U);
		JumpToApplication = (pFunction) JumpAddress;
		__disable_irq();
		__set_MSP(bootloader_sp);
		JumpToApplication();
		while (1) {
		}
	}
	*dfu_boot_flag = 0; // So next boot won't be affected

  /* USER CODE END 1 */

  /* MCU Configuration--------------------------------------------------------*/

  /* Reset of all peripherals, Initializes the Flash interface and the Systick. */
  HAL_Init();

  /* Configure the system clock */
  SystemClock_Config();

  /* USER CODE BEGIN SysInit */
	/* Enable and set FLASH Interrupt priority */
	/* FLASH interrupt is used for the purpose of pages clean up under interrupt */
	HAL_NVIC_SetPriority(FLASH_IRQn, 0, 0);
	HAL_NVIC_EnableIRQ(FLASH_IRQn);

	/* Unlock the Flash Program Erase controller */
	HAL_FLASH_Unlock();
	/* Activate NMI generation when two errors are detected */
	__HAL_FLASH_ENABLE_IT(FLASH_IT_ECCC);

  /* USER CODE END SysInit */

  /* Initialize all configured peripherals */
  MX_GPIO_Init();
  if (bootloaderButtonHeldAtStartup() != 0U) {
	  Bootloader_RequestReset();
  }
  MX_DMA_Init();
  MX_ADC1_Init();
  MX_I2C2_Init();
  MX_TIM2_Init();
  MX_UCPD1_Init();
  MX_IWDG_Init();
  MX_CRC_Init();
  /* USER CODE BEGIN 2 */
	InitDisplay();
	ee_status = EE_Init(EE_FORCED_ERASE);
	if (ee_status != EE_OK) {
		displayEepromIssue();
	} else {
		EE_Read_Color(1);
	}

  /* USER CODE END 2 */

  /* Init scheduler */
  osKernelInitialize();
  /* USBPD initialisation ---------------------------------*/
  MX_USBPD_Init();
  MX_TCPP_Init();

  /* USER CODE BEGIN RTOS_MUTEX */
	/* add mutexes, ... */
  /* USER CODE END RTOS_MUTEX */

  /* USER CODE BEGIN RTOS_SEMAPHORES */
	/* add semaphores, ... */
  /* USER CODE END RTOS_SEMAPHORES */

  /* USER CODE BEGIN RTOS_TIMERS */
	/* start timers, add new ones, ... */
  /* USER CODE END RTOS_TIMERS */

  /* USER CODE BEGIN RTOS_QUEUES */
	/* add queues, ... */
  /* USER CODE END RTOS_QUEUES */

  /* Create the thread(s) */
  /* creation of defaultTask */
  defaultTaskHandle = osThreadNew(StartDefaultTask, NULL, &defaultTask_attributes);

  /* USER CODE BEGIN RTOS_THREADS */
	encoderTaskHandle = osThreadNew(EncoderTask, NULL, &encoderTask_attributes);

	/* add threads, ... */
  /* USER CODE END RTOS_THREADS */

  /* USER CODE BEGIN RTOS_EVENTS */
	/* add events, ... */
  /* USER CODE END RTOS_EVENTS */

  /* Start scheduler */
  osKernelStart();

  /* We should never get here as control is now taken by the scheduler */

  /* Infinite loop */
  /* USER CODE BEGIN WHILE */
	while (1) {
    /* USER CODE END WHILE */

    /* USER CODE BEGIN 3 */
	}
  /* USER CODE END 3 */
}

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
/* USER CODE BEGIN 4 */
// restart into the bootloader by setting the correct option bytes and then trigger reset
/* USER CODE BEGIN Header_StartDefaultTask */
/**
 * @brief  Function implementing the defaultTask thread.
 * @param  argument: Not used
 * @retval None
 */
/* USER CODE END Header_StartDefaultTask */
void StartDefaultTask(void *argument)
{
  /* init code for USB_Device */
  MX_USB_Device_Init();
  /* USER CODE BEGIN 5 */
	HAL_TIM_PWM_Start(&htim2, TIM_CHANNEL_1);
	HAL_TIM_PWM_Start(&htim2, TIM_CHANNEL_2);
	HAL_TIM_PWM_Start(&htim2, TIM_CHANNEL_3);
	TIM2->ARR = PWM_TIMER_PERIOD;
	TIM2->CCR1 = 0;
	TIM2->CCR2 = 0;
	TIM2->CCR3 = 0;
	camera_detect_last_sample = readCameraDetectState();
	camera_mode_active = camera_detect_last_sample;
	camera_detect_last_transition = osKernelGetTickCount();
	/* Infinite loop */

	for (;;) {
		uint8_t leds_can_run;
		HAL_IWDG_Refresh(&hiwdg);
		refreshPDPowerState();
		refreshCameraModeState();
		updateScreen();
		leds_can_run = (on != 0U) && (pd_20v_ready != 0U);
		pwm[0] = leds_can_run ? mapColorToPwmDuty(colors[0]) : 0U;
		pwm[1] = leds_can_run ? mapColorToPwmDuty(colors[1]) : 0U;
		pwm[2] = leds_can_run ? mapColorToPwmDuty(colors[2]) : 0U;
		TIM2->CCR1 = pwm[0];
		TIM2->CCR2 = pwm[1];
		TIM2->CCR3 = pwm[2];
		osDelay(100);
	}
  /* USER CODE END 5 */
}

/**
  * @brief  Period elapsed callback in non blocking mode
  * @note   This function is called  when TIM3 interrupt took place, inside
  * HAL_TIM_IRQHandler(). It makes a direct call to HAL_IncTick() to increment
  * a global variable "uwTick" used as application time base.
  * @param  htim : TIM handle
  * @retval None
  */
void HAL_TIM_PeriodElapsedCallback(TIM_HandleTypeDef *htim)
{
  if (htim->Instance == TIM3)
  {
    HAL_IncTick();
  }
}

/**
  * @brief  This function is executed in case of error occurrence.
  * @retval None
  */
void Error_Handler(void)
{
  /* USER CODE BEGIN Error_Handler_Debug */
	/* User can add his own implementation to report the HAL error return state */
	__disable_irq();
	while (1) {
	}
  /* USER CODE END Error_Handler_Debug */
}
#ifdef USE_FULL_ASSERT
/**
  * @brief  Reports the name of the source file and the source line number
  *         where the assert_param error has occurred.
  * @param  file: pointer to the source file name
  * @param  line: assert_param error line source number
  * @retval None
  */
void assert_failed(uint8_t *file, uint32_t line)
{
  /* USER CODE BEGIN 6 */
  /* User can add his own implementation to report the file name and line number,
     ex: printf("Wrong parameters value: file %s on line %d\r\n", file, line) */
  /* USER CODE END 6 */
}
#endif /* USE_FULL_ASSERT */

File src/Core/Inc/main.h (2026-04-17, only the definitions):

#define VDDA_APPLI 3300
#define R_SW_Pin GPIO_PIN_3
#define R_SW_GPIO_Port GPIOA
#define R_Q_Pin GPIO_PIN_4
#define R_Q_GPIO_Port GPIOA
#define R_I_Pin GPIO_PIN_5
#define R_I_GPIO_Port GPIOA
#define VSENSE_Pin GPIO_PIN_10
#define VSENSE_GPIO_Port GPIOB
#define SHUTTER_Pin GPIO_PIN_11
#define SHUTTER_GPIO_Port GPIOB
#define FOCUS_Pin GPIO_PIN_12
#define FOCUS_GPIO_Port GPIOB
#define CAMERA_DETECT_Pin GPIO_PIN_13
#define CAMERA_DETECT_GPIO_Port GPIOB
#define FLT_IN_Pin GPIO_PIN_9
#define FLT_IN_GPIO_Port GPIOA
#define DB_OUT_Pin GPIO_PIN_6
#define DB_OUT_GPIO_Port GPIOC
#define R_GPIO_Port GPIOA
#define R_IQSW_Pins (R_SW_Pin | R_Q_Pin | R_I_Pin)
#define R_IQ_Pins R_Q_PIN | R_I_PIN
#define PWM_R_Pin GPIO_PIN_0
#define PWM_R_Port GPIOA
#define PWM_G_Pin GPIO_PIN_1
#define PWM_G_Port GPIOA
#define PWM_B_Pin GPIO_PIN_2
#define PWM_B_Port GPIOA
#define SDA_Pin GPIO_PIN_6
#define SDA_Port GPIOA
#define SCL_Pin GPIO_PIN_7
#define SDA_Port GPIOA

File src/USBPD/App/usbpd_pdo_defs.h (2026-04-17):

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

#ifndef __USBPD_PDO_DEF_H_
#define __USBPD_PDO_DEF_H_

#ifdef __cplusplus
 extern "C" {
#endif

/* Includes ------------------------------------------------------------------*/
#include "usbpd_def.h"

/* Define   ------------------------------------------------------------------*/
#define PORT0_NB_SOURCEPDO         0U   /* Number of Source PDOs (applicable for port 0)   */
#define PORT0_NB_SINKPDO           1U   /* Number of Sink PDOs (applicable for port 0)     */
/* Exported typedef ----------------------------------------------------------*/
/* USER CODE BEGIN typedef */
/**
 * @brief  USBPD Port PDO Structure definition
 *
 */

/**
 * @brief  USBPD Port PDO Structure definition
 */
typedef struct {
	uint32_t *ListOfPDO; /*!< Pointer on Power Data Objects list, defining port capabilities */
	uint8_t *NumberOfPDO; /*!< Number of Power Data Objects defined in ListOfPDO
	 This parameter must be set at max to @ref USBPD_MAX_NB_PDO value */
} USBPD_PortPDO_TypeDef;

/**
 * @brief  USBPD Port PDO Storage Structure definition
 */

typedef struct {
	USBPD_PortPDO_TypeDef SourcePDO; /*!< SRC Power Data Objects */
	USBPD_PortPDO_TypeDef SinkPDO; /*!< SNK Power Data Objects */

} USBPD_PWR_Port_PDO_Storage_TypeDef;
/* USER CODE END typedef */

/* Exported define -----------------------------------------------------------*/
/* USER CODE BEGIN Exported_Define */

#define USBPD_CORE_PDO_SRC_FIXED_MAX_CURRENT 3
#define USBPD_CORE_PDO_SNK_FIXED_MAX_CURRENT 1250

/* USER CODE END Exported_Define */

/* Exported constants --------------------------------------------------------*/

/* Exported macro ------------------------------------------------------------*/

/* Exported variables --------------------------------------------------------*/
/* USER CODE BEGIN variables */

#ifndef _GUI_INTERFACE
#ifndef __USBPD_PWR_IF_C
extern uint8_t USBPD_NbPDO[4];
extern uint32_t PORT0_PDO_ListSRC[USBPD_MAX_NB_PDO];
extern uint32_t PORT0_PDO_ListSNK[USBPD_MAX_NB_PDO];
#else /* __USBPD_PWR_IF_C */
uint8_t USBPD_NbPDO[4] = {(PORT0_NB_SINKPDO),
                          (PORT0_NB_SOURCEPDO)};
#endif /* __USBPD_PWR_IF_C */
#endif /* _GUI_INTERFACE */

/* USER CODE END variables */

#ifndef __USBPD_PWR_IF_C
extern uint32_t PORT0_PDO_ListSRC[USBPD_MAX_NB_PDO];
extern uint32_t PORT0_PDO_ListSNK[USBPD_MAX_NB_PDO];
#else
/* Definition of Source PDO for Port 0 */
uint32_t PORT0_PDO_ListSRC[USBPD_MAX_NB_PDO] =
{
  /* PDO 1 */ (0x00000000U),
  /* PDO 2 */ (0x00000000U),
  /* PDO 3 */ (0x00000000U),
  /* PDO 4 */ (0x00000000U),
  /* PDO 5 */ (0x00000000U),
  /* PDO 6 */ (0x00000000U),
  /* PDO 7 */ (0x00000000U),
};

/* Definition of Sink PDO for Port 0 */
uint32_t PORT0_PDO_ListSNK[USBPD_MAX_NB_PDO] =
{
  /* PDO 1 */
  (
    USBPD_PDO_TYPE_FIXED                 | /* Fixed supply PDO            */

    USBPD_PDO_SNK_FIXED_SET_VOLTAGE(20000U)         | /* Voltage in mV               */
    USBPD_PDO_SNK_FIXED_SET_OP_CURRENT(1250U)     | /* Operating current in  mA            */

    /* Common definitions applicable to all PDOs, defined only in PDO 1 */
    USBPD_PDO_SNK_FIXED_FRS_NOT_SUPPORTED          | /* Fast Role Swap				 */
    USBPD_PDO_SNK_FIXED_DRD_SUPPORTED          | /* Dual-Role Data              */
    USBPD_PDO_SNK_FIXED_USBCOMM_SUPPORTED      | /* USB Communications          */
    USBPD_PDO_SNK_FIXED_EXT_POWER_NOT_AVAILABLE    | /* External Power              */
    USBPD_PDO_SNK_FIXED_HIGHERCAPAB_NOT_SUPPORTED   | /* Higher Capability           */
    USBPD_PDO_SNK_FIXED_DRP_NOT_SUPPORTED            /* Dual-Role Power             */
  ),
  /* PDO 2 */ (0x00000000U),
  /* PDO 3 */ (0x00000000U),
  /* PDO 4 */ (0x00000000U),
  /* PDO 5 */ (0x00000000U),
  /* PDO 6 */ (0x00000000U),
  /* PDO 7 */ (0x00000000U),
};

#endif

/* Exported functions --------------------------------------------------------*/

#ifdef __cplusplus
}
#endif

#endif /* __USBPD_PDO_DEF_H_ */

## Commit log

2025-03-20 PCB for 4x5 scanlight
    [backlight-B_Cu.gbl, backlight-B_Mask.gbs, backlight-B_Paste.gbp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]
2025-03-20 4x5 version of 3d printed parts
    [24d-p0010 diffuser housing.SLDPRT, 24d-p0010 diffuser housing.STL, 24d-p0020 diffuser cover plate.SLDPRT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]
2025-03-20 STM32 Project
2025-06-02 booting correctly with DFU jump and USBPD working
    [main.c, main.h, scanlight.ioc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]
2026-04-17 finalized schematic v2, add GS cap for inrush current
    [backlight.kicad_pcb, backlight.kicad_sch, leds.kicad_sch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]
2026-04-17 More stable USBPD code, add camera capture with 2.5mm jack remote
2026-04-28 Update readme and current functionality
    [backlight.kicad_pcb]

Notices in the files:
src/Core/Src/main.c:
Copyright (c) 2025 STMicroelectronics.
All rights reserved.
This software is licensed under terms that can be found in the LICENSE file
